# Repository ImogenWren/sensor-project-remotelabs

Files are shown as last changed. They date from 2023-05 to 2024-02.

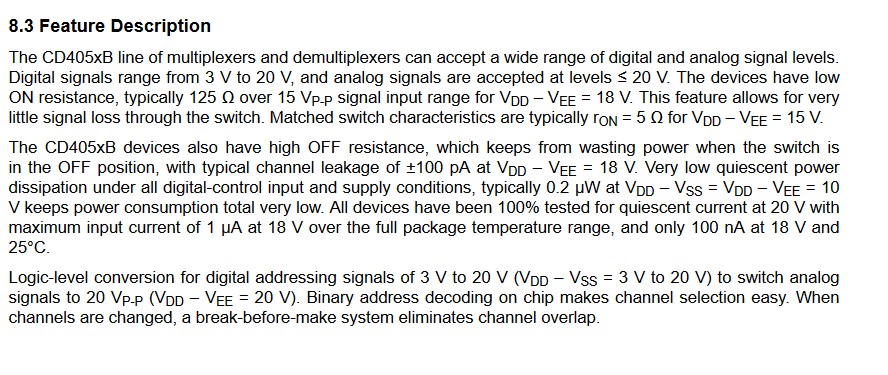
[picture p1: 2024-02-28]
CD4051-feature-description.jpg

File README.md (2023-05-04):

# Sensors One - sensors-backbone-pcb - Power Supply 

## Description
The backbone PCB will provide all power requirements to the sensors One experiment. It will manage routing the PicoScope probes to defined pins on the backbone header, which will join the backbone PCB to the sensors one experiment PCB. This document outlines the power distribution section of the system, and will define the requirements for power supplied to the sensors-backbone-pcb.

## Power Requirements

### Sensors Experiment Power Requirements
_All power requirements for the **sensors-one-pcb** must be provided by **sensors-backbone-pcb**_

#### Bi-polar Op-Amp Supply
- Bi-polar supply for Op-Amps and similar (100mA per 5v rail (+-)? is this enough)
#### 5v Fan
- Power for Fan (?mA @ 5v) PWM Capable
	- Fan Option A: Cheap but no data
		- https://www.unmannedtechshop.co.uk/product/40mm-cooling-fan-5v-pwm-adjustable/
	- Fan Option B: Expensive but has whitepaper with full specifications:
		- 0.35 W
		- 70 mA @ 5v
		- https://www.quietpc.com/nf-a4x10-5v-pwm
		- https://noctua.at/pub/media/wysiwyg/Noctua_PWM_specifications_white_paper.pdf
		- Also have a 2 pulse per revolution output that can be used to sense RPM
#### Torch Bulb
- Power for Bulb. (~60mA @ ~5v)
	- 	https://www.switchelectronics.co.uk/6v-60ma-miniature-e10-mes-lamp-bulb

#### Additional Power Requirements
- #TODO: Any MCU required on experiment board?

## SUMMARY: sensors-one-pcb power Requirements
- Bi-Polar (+-)5v DC up to 100mA each rail
- High Current 5v (At least 200mA)

### Backbone PCB Power Requirements
_Power Requirements for all hardware on **sensors-backbone-pcb**
- Embedded MCU (200mA max @ 5v)
- analog switch power requirements
	- Quiecient current ~ 6 uA 
	- Assume that this is within spec for MCU
- any other board level hardware
- +5v for SBC. 3A specified.

## Power Distribution - sensors-backbone-pcb
_Detail suitable options for providing for each of the power requirements_

### To Sensors One
-(+-)5v will be provided using linear or switching power regulators or similar.
- +5v High Current will be provided using regulator or buck converter
### For Local Use
- +5v for SBC will be provided via a buck converter capable of 3A output @ 5v 
- +5v for Embedded Systems provided by Buck Converter or Regulator (Could this be shared with sensors 1 high current?)

## Power Distro Parts Specification
_Specify specific solutions for each power requirement_

### Bi-Polar Power Supply

#### (+-5v) Bi-Polar Supply for sensors-one-pcb - OPTION A
https://uk.rs-online.com/web/p/dc-dc-converters/1227021
https://docs.rs-online.com/2f4c/0900766b8154511b.pdf
Specs:
- Vout 			= +-5v 
- Power Rating 	= 1W
- Iout(max) 	= 200mA (100mA per output)
- Vdropout		= n/a
- Package 		= SIP
- Vin(min)	 	= 4.5  (check datasheet - 12v and 24VDC in models available
- Vin(max) 		= 5.5 
- Efficiency 	= 83%
- Cost			= £4.01
- Inoload		= 20mA
Assuming 24VDC input and 200mA output = 5x0.2 = 1W, with efficiency this means: 50mA @ 24v

If this power supply is too small then ->

###  Option D Negative Buck Converter
https://www.vishay.com/docs/76946/creatingnegativeoutputvoltage.pdf

### High Current 5v supply

#### Buck Converter
- Same as ISOpower board

Vin: 24VDC
Vout: 5vDC
Iout: 3A
Pout: 15W
Efficiency ~ 0.80
Pmax = Pout/0.80 = 18.75W
Iin =  18.75/24 = 0.78125 A 780.125 mA

#### Switching Regulator
- Same as supervisor PCB

https://recom-power.com/pdf/Innoline/R-78C-1.0.pdf

Vin: 7 - 42 (24v)
Vout: 5 vDC
Iout: 1 A
Pout: 5 W
Efficiency  0.85
Pmax = Pout/0.85 = 6 W
Iin =  6/24 = 0.25 A 250 mA

### SBC Power Supply

#### (+5v) Buck Converter for SBC
- Same as ISOpower board

Vin: 24VDC
Vout: 5vDC
Iout: 3A
Pout: 15W
Efficiency ~ 0.80
Pmax = Pout/0.80 = 18.75W
Iin =  18.75/24 = 0.78125 A 780.125 mA

### Embedded MCU and Associated circuits (inc switches)
Any reason to keep this seperate from the high current supply - Especially if using buck converter?

Assuming that it is seperate just for Max Current Calculations

## Power Input Requirements to sensor-backbone-pcb
_Ensure that all specified hardware can be provided +24v, and calculate *Itotal* for 24v input_

For sensors-one-pcb:
- Bi-Polar Supply 
	- 50mA max @ 24v
- High Current (using worse case scenario):
	- 800mA @ 24v
For Embedded System sensors-backbone-pcb:
	- 800mA @ 24v
For SBC
	- 800mA max @ 24v

## Total Power Requirement for sensors-backbone-pcb
 2.5 A @ 24 V
 
 Design spec for 3 A

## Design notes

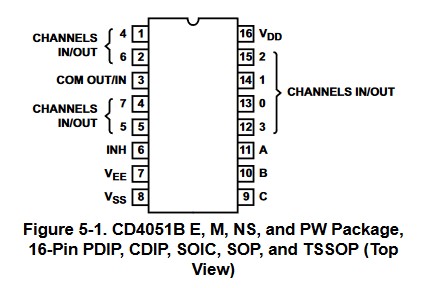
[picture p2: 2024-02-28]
CD4051-pinout.jpg

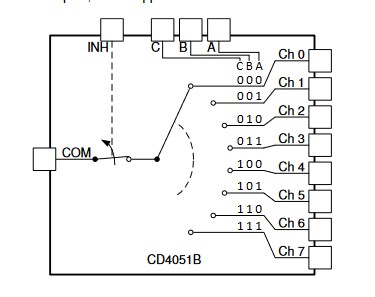
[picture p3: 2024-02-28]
CD4051-internal-schematic.jpg

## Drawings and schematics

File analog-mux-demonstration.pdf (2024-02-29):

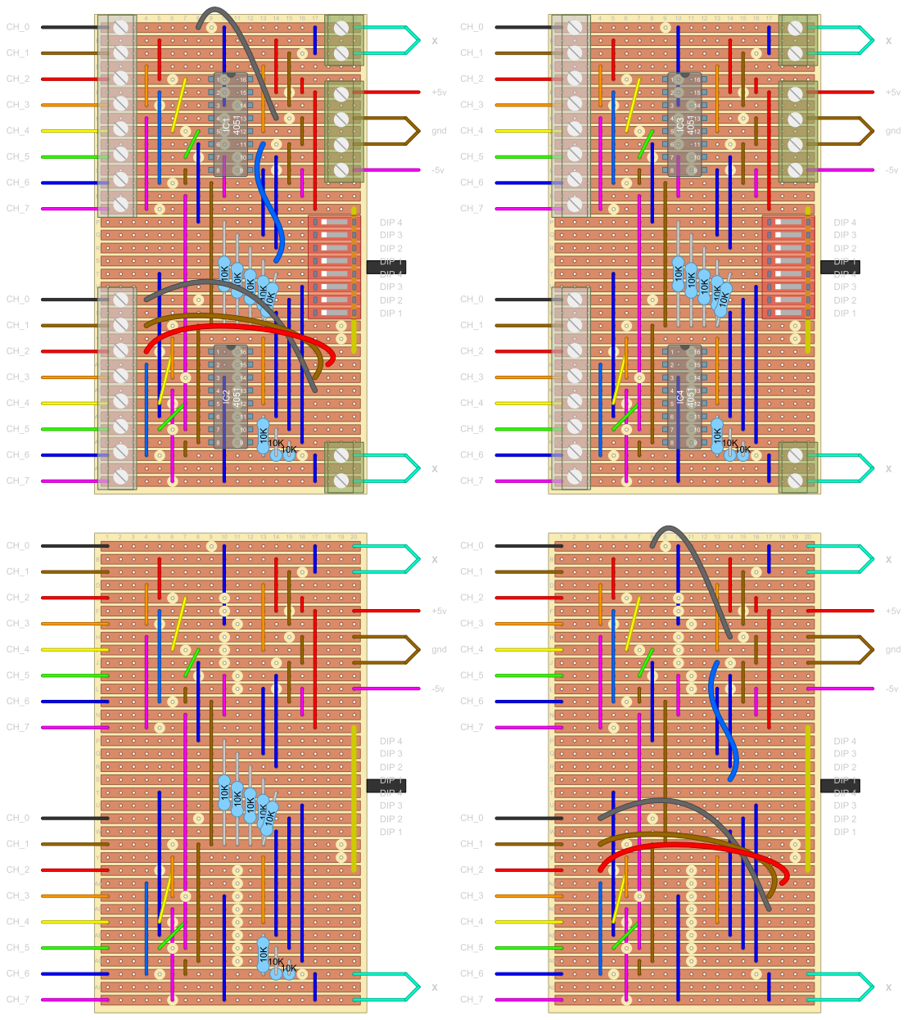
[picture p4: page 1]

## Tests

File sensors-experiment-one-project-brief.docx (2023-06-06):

# ## Sensors Project – Experiment One - Brief

# 1 Introduction

The aim of this project is to develop an experiment to explore a range of measurements that can be undertaken on a simple circuit, including measurement of temperature in order to deduce the power transferred through different waveforms.

# 2 Equipment

The experiment will use the following equipment:

- PicoScope 2000
- Ohmic load (Resistor)
- Non-Ohmic load (incandescent bulb?)
- PWM Controllable Fan
- Suitable analog temperatures sensors
- Suitable digital temperature sensor for calibration of analog sensors

# 3 Experiment Concept

The concept for this experiment is to use simple circuit elements in order to take a range of different measurements using the PicoScope, and develop a range of experiments that can be undertaken using the same equipment and circuits. Some ideas are listed below.

### 3.1.1 Power Transfer Experiment

Measure the change of temperature of different loads, when current is supplied using different waveforms, DC, Sine, Sawtooth or Square. Calculate the efficiency of the power transfer.

### 3.1.2 Changing Resistance with Temperature

Measure voltages around the circuit to deduce the value of the loads. Repeat measurements at different temperatures. Compare Ohmic load to non Ohmic load.

### 3.1.3 PID Temperature Controller

Use a PWM controllable fan to implement a PID temperature controller.

## 3.1 Other Sensors to Consider

- Light gate to measure fan rotation speed
- Anemometer to measure fan wind speed

## 3.2 Circuit Concept

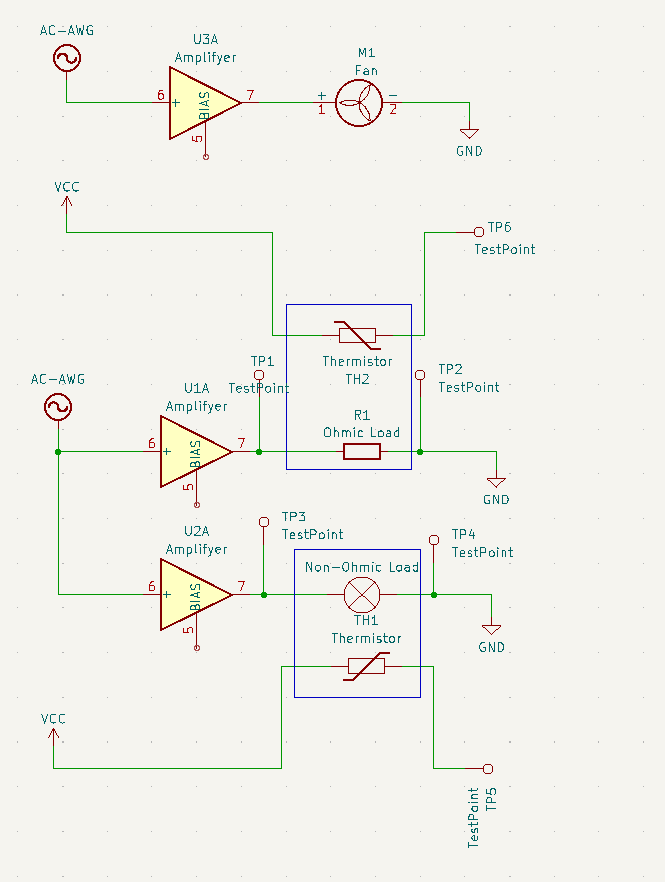
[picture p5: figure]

*Note circuit is high level concept only, full implementation needs to be developed.

*Test points show potential placement for PicoScope probes.

# 4 Constraints

- All PicoScope signals must be constrained to ±5 V
- Voltage supplied to the circuit will be ±5 V
- No more than 100mA Current draw max from either +5 V or -5V bus.
- Additional High Current 5v supply will be provided for high current loads. (i.e. heating elements, bulbs, fans). No more than 1.5A should be drawn from this supply.

# 5 Deliverables

This project will be broken down into the following deliverables with a timeframe to be arranged between student and supervisors.

## 5.1 Define Experiments to Develop

- The student should develop a list of experiments that could be undertaken with the specified hardware, and provide rational for the data that could be collected, how it could be processed and what learning outcomes can be derived from these experiments.
- Take inspiration from the suggestions above, but free to come up with alternatives or modify to suit better learning outcomes.

## 5.2 Completed Schematic

- Student must take into account signal constraints, signal noise and power consumption to derive a schematic with suitable parts values to perform the experiments outlined above, while meeting the constraints given.

## 5.3 Prototype Experimental Setup

- Breadboarded setup of the above schematic to show reliability of measurements, and repeatability of the experimental setup.
- Define procedure for physical assembly, mounting of sensors to test articles etc.
- Work with STO to help define PCB layout.

## 5.4 Mathematical Model

- Develop a mathematical model to accompany the experimental setup.
- Show how typical results differ from idealised model and explain rational behind the differences.

Imogen Heard RemoteLabs – Sensors Project - Experiment One - Brief Tuesday, 16 May 2023

Student Declaration of Authorship

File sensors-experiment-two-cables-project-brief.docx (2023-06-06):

# # Sensors Project – Experiment Two: Cables & Data Transmission Experiment - Brief

# 1 Introduction

The objective of this project is to create an experiment that investigates various measurements on different cable types, aiming to determine how the construction and in-circuit implementation of these cables can affect the measurable signal to noise ratio.

# 2 Equipment

The experiment will use the following equipment:

- PicoScope 2000
- Suitable range of different cables
- A source of wide band E.M.F noise
- Analog switches/gates/multiplexers

# 3 Experiment Concept

The idea behind this experiment involves introducing noise to different cable constructions and measuring the resulting signal's signal to noise ratio (SNR). Since several aspects of this process are unproven, the development phase will need to meticulously explore various details to establish the experiment's viability. Although this investigation is open-ended, the following sections lists several areas that are likely worth exploring and collecting experimental data on.

# 4 Potential Experiments

This section records potential ideas that we consider interesting for developing experiments; utilizing this equipment for remote laboratories. This should be considered a general guide, if investigation leads to alternatives, they should also be explored and discussed.

## 4.1 Shielded Cable Implementation

- Compare SNR between:
  - Single core cable
  - Screened/shielded cable – ungrounded
  - Screened/Shielded cable – grounded at a single end
  - Screened/Shielded cable – grounded at each end

## 4.2 Twisted vs non twisted pairs

- Compare data transmission fidelity over twisted and non-twisted pairs
- Investigate EMF transmitted from twisted/non twisted pairs.

## 4.3 CAT5 cable

## 4.4 Comparing quality of cables

- RF / Audio spec cable comparison. (may be hampered by low bandwidth of PicoScope)

## 4.5 Cable isolated from ground planes vs run along ground planes

- Prove the audiophiles correct, does lifting a cable off the ground increase SNR?

# 5 Potential Areas of Investigation

This section records unknown aspects that may affect the development and implementation of the above experiments. These unknowns should be explored before continuing further development towards the remote labs experiment in order to mitigate risk and guide the development process.

## 5.1 Ease of using PicoScope for SNR measurements

- Take a range of measurements using a PicoScope to deduce the usefulness of this equipment for this purpose.

## 5.2 Analog Switching for grounding

- For experiments that require grounded and ungrounded connections
- Is this possible to achieve with analog mux ICs, MOSFETS or BJTs?
- Is an open collector the same as a floating wire?
- Alternative methods for switching PicoScope probes to different parts of the circuit
- RF switches – see VNA experiment

## 5.3 Reliable EMF noise source

- What is a suitable controllable source of EMF noise?
- Is background noise enough for experimental outcomes?
- Does this change once experiment is inside metal enclosure?

# 6 Constraints

- All PicoScope signals must be constrained to ±5 V
- Voltage supplied to the circuit will be ±5 V
- No more than 100mA Current draw max from either +5 V or -5V bus.
- Additional High Current 5v supply will be provided for high current loads. (i.e. heating elements, bulbs, fans). No more than 1.5A should be drawn from this supply.

# 7 Deliverables

This project will be broken down into the following deliverables with a timeframe to be arranged between intern and supervisors.

## 7.1 Conduct investigation into experimental unknowns

- Expand on list of unknown quantities in sensors 2 experiment concept
- Write a short report detailing investigation into unknown quantities.
  - Report should detail facts gathered, workarounds to any potential issues found, and suggestions for experimental development.

## 7.2 Design Experiment

- Take into account lessons learned in previous exercise to develop an experimental concept to develop into a prototype.
- Develop schematic and test procedure that takes into account the constraints of the equipment and remote labs environment.

## 7.3 Prototype Experimental Setup

- Breadboarded setup of the above schematic to show reliability of measurements, and repeatability of the experimental setup.
- Define procedure for physical assembly, mounting of sensors to test articles etc.
- Work with STO to help define PCB layout.

## 7.4 Mathematical Model

- Stretch goal
- Develop a mathematical model to accompany the experimental setup.
- Show how typical results differ from idealised model and explain rational behind the differences.

Imogen Heard RemoteLabs – Sensors Project - Experiment Two - Brief Tuesday, 06 June 2023

Student Declaration of Authorship

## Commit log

2023-05-03 changed names
    [power-supply.kicad_sch, sensors-backbone-pcb.kicad_pcb, sensors-backbone-pcb.kicad_sch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]
2023-05-04 Added README for power distribution design
    [sensors-backbone-pcb.kicad_sch]
2024-02-28 added test board start
    [analog-multiplexer-eval.kicad_pcb, analog-multiplexer-eval.kicad_sch]
